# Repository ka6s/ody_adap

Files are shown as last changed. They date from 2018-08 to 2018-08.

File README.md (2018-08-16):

# Odyssey-II adapter
This is a break out board for the Oddyssey II HPSDR transceiver.

I have done a couple of versions of this - the final configuration has a SPI output, but also
expects to be able to support a x4 HERMES style filter set up.  There is also a custom 
connector on here to drive the companion antenna switch. Note that there is only ONE 
ANT output available - so only two antenna ports are supported.

Lots of copies of PTT-out..can't have too many of those!

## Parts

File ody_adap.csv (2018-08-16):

Id | Designator | Package | Quantity | Designation | Supplier and ref
1 | J1 | DB15_Male_HighDensity | 1 | DB15_Male_HighDensity
2 | R5,R1,R3,R4,R6,R7,R8,R9,R10,R11,R12 | R_1206_HandSoldering | 11 | 10K
3 | C6,C9,C12 | C_1210_HandSoldering | 3 | 100uF
4 | C7,C10,C13 | C_1210_HandSoldering | 3 | 1uF
5 | C8,C11 | C_1206_HandSoldering | 2 | 0.1uF
6 | C14 | C_1206 | 1 | 0.1uF
7 | CON1 | BARREL_JACK | 1 | BARREL_JACK
8 | P1,P2,P3,P4,P8,P9,P10 | Pin_Header_Straight_1x03 | 7 | CONN_01X03
9 | P5,P6,P7 | Pin_Header_Straight_2x04 | 3 | CONN_02X04
10 | Q1,Q2,Q3 | TO-92_Molded_Narrow | 3 | Q_NMOS_SGD
11 | U1,U2 | DIP-16_W7.62mm | 2 | ULN2003
12 | J2 | Pin_Header_Straight_1x06_Pitch2.54mm | 1 | Conn_01x06
13 | P11 | Pin_Header_Straight_1x03_Pitch2.54mm | 1 | CONN_01X03
14 | P12 | Pin_Header_Straight_1x05_Pitch2.54mm | 1 | CONN_01X05

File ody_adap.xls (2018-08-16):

Id | Designator | Package | Quantity | Designation | Mouser
1 | J1 | DB15_Male_HighDensity | 1 | DB15_Male_HighDensity
2 | R5,R1,R3,R4,R6,R7,R8,R9,R10,R11,R12 | R_1206_HandSoldering | 11 | 10K | 66-PCFW1206LF031002B (https://www.mouser.com/ProductDetail/Welwyn-Components-TT-Electronics/PCF-W1206LF-03-1002-B-P-LT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)
3 | C6,C9,C12 | C_1210_HandSoldering | 3 | 100uF | 963-EMK325ABJ107MM-T (https://www.mouser.com/ProductDetail/Taiyo-Yuden/EMK325ABJ107MM-T)
4 | C7,C10,C13 | C_1210_HandSoldering | 3 | 1uF | 77-VJ1206Y105KXQTBC (https://www.mouser.com/QuickViewProdDetail.aspx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)
5 | C8,C11 | C_1206_HandSoldering | 2 | 0.1uF | 963-QMK316BJ104KL-T (https://www.mouser.com/ProductDetail/Taiyo-Yuden/QMK316BJ104KL-T)
6 | C14 | C_1206 | 1 | 0.1uF | 963-QMK316BJ104KL-T (https://www.mouser.com/ProductDetail/Taiyo-Yuden/QMK316BJ104KL-T)
7 | CON1 | BARREL_JACK | 1 | BARREL_JACK | 490-PJ-002BH (https://www.mouser.com/QuickViewProdDetail.aspx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)
8 | P1,P2,P3,P4,P8,P9,P10 | Pin_Header_Straight_1x03 | 7 | CONN_01X03
9 | P5,P6,P7 | Pin_Header_Straight_2x04 | 3 | CONN_02X04
10 | Q1,Q2,Q3 | TO-92_Molded_Narrow | 3 | Q_NMOS_SGD | 512-2N7000 (https://www.mouser.com/QuickViewProdDetail.aspx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)
11 | U1,U2 | DIP-16_W7.62mm | 2 | ULN2003 | 511-ULN2003A (https://www.mouser.com/ProductDetail/STMicroelectronics/ULN2003A?qs=sGAEpiMZZMvAvBNgSS9LqkBZ7AC8MBp%2F)
12 | J2 | Pin_Header_Straight_1x06_Pitch2.54mm | 1 | Conn_01x06
13 | P11 | Pin_Header_Straight_1x03_Pitch2.54mm | 1 | CONN_01X03
14 | P12 | Pin_Header_Straight_1x05_Pitch2.54mm | 1 | CONN_01X05

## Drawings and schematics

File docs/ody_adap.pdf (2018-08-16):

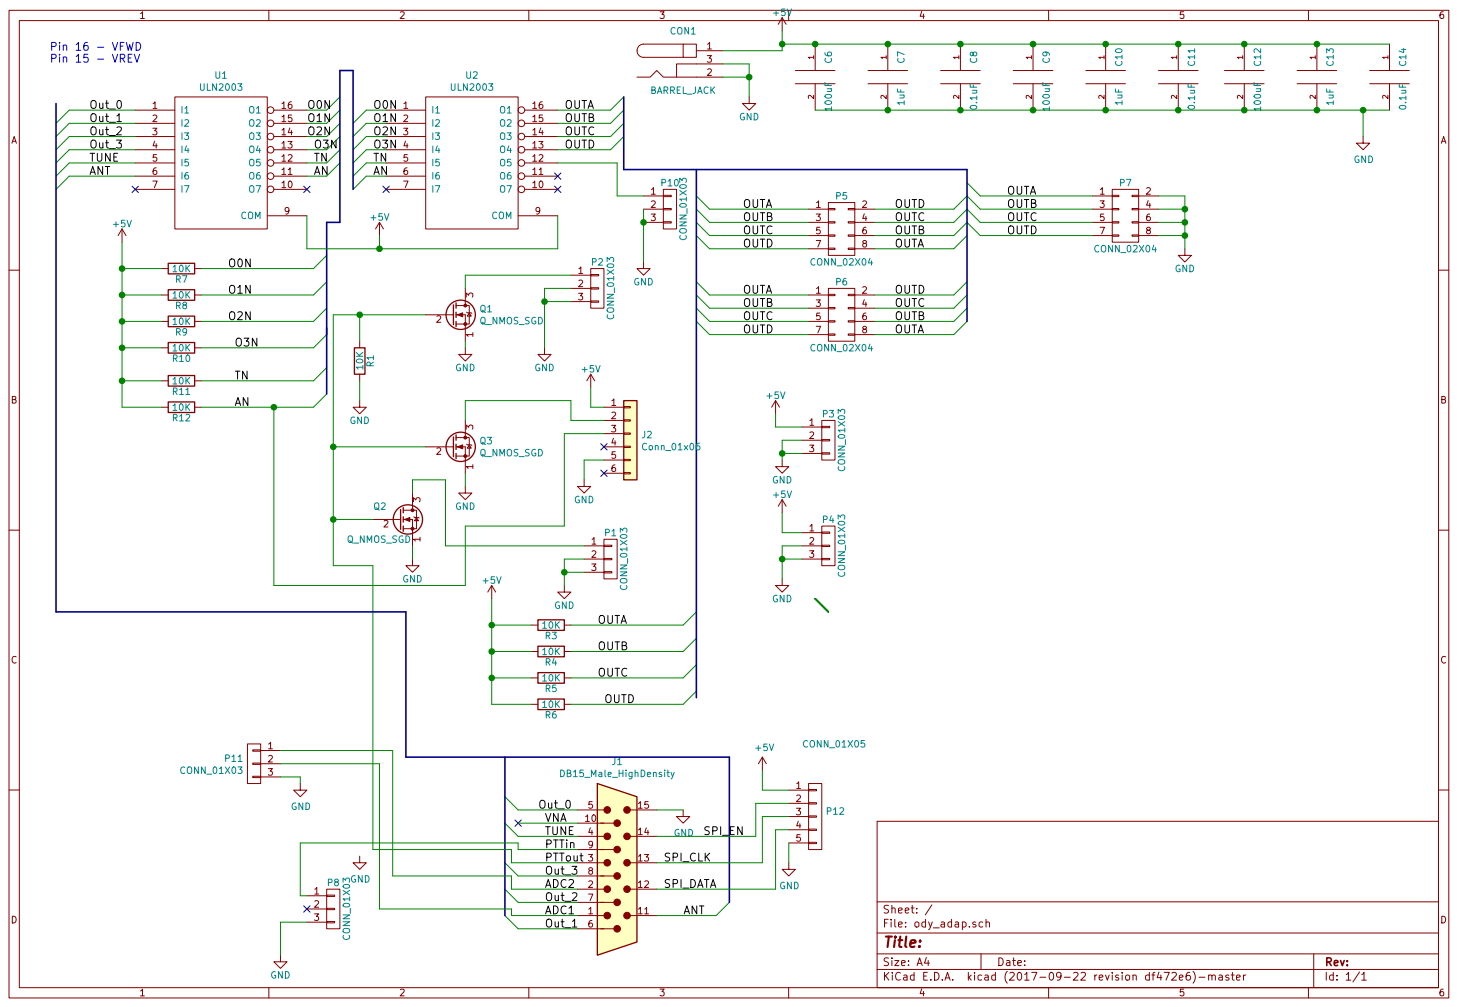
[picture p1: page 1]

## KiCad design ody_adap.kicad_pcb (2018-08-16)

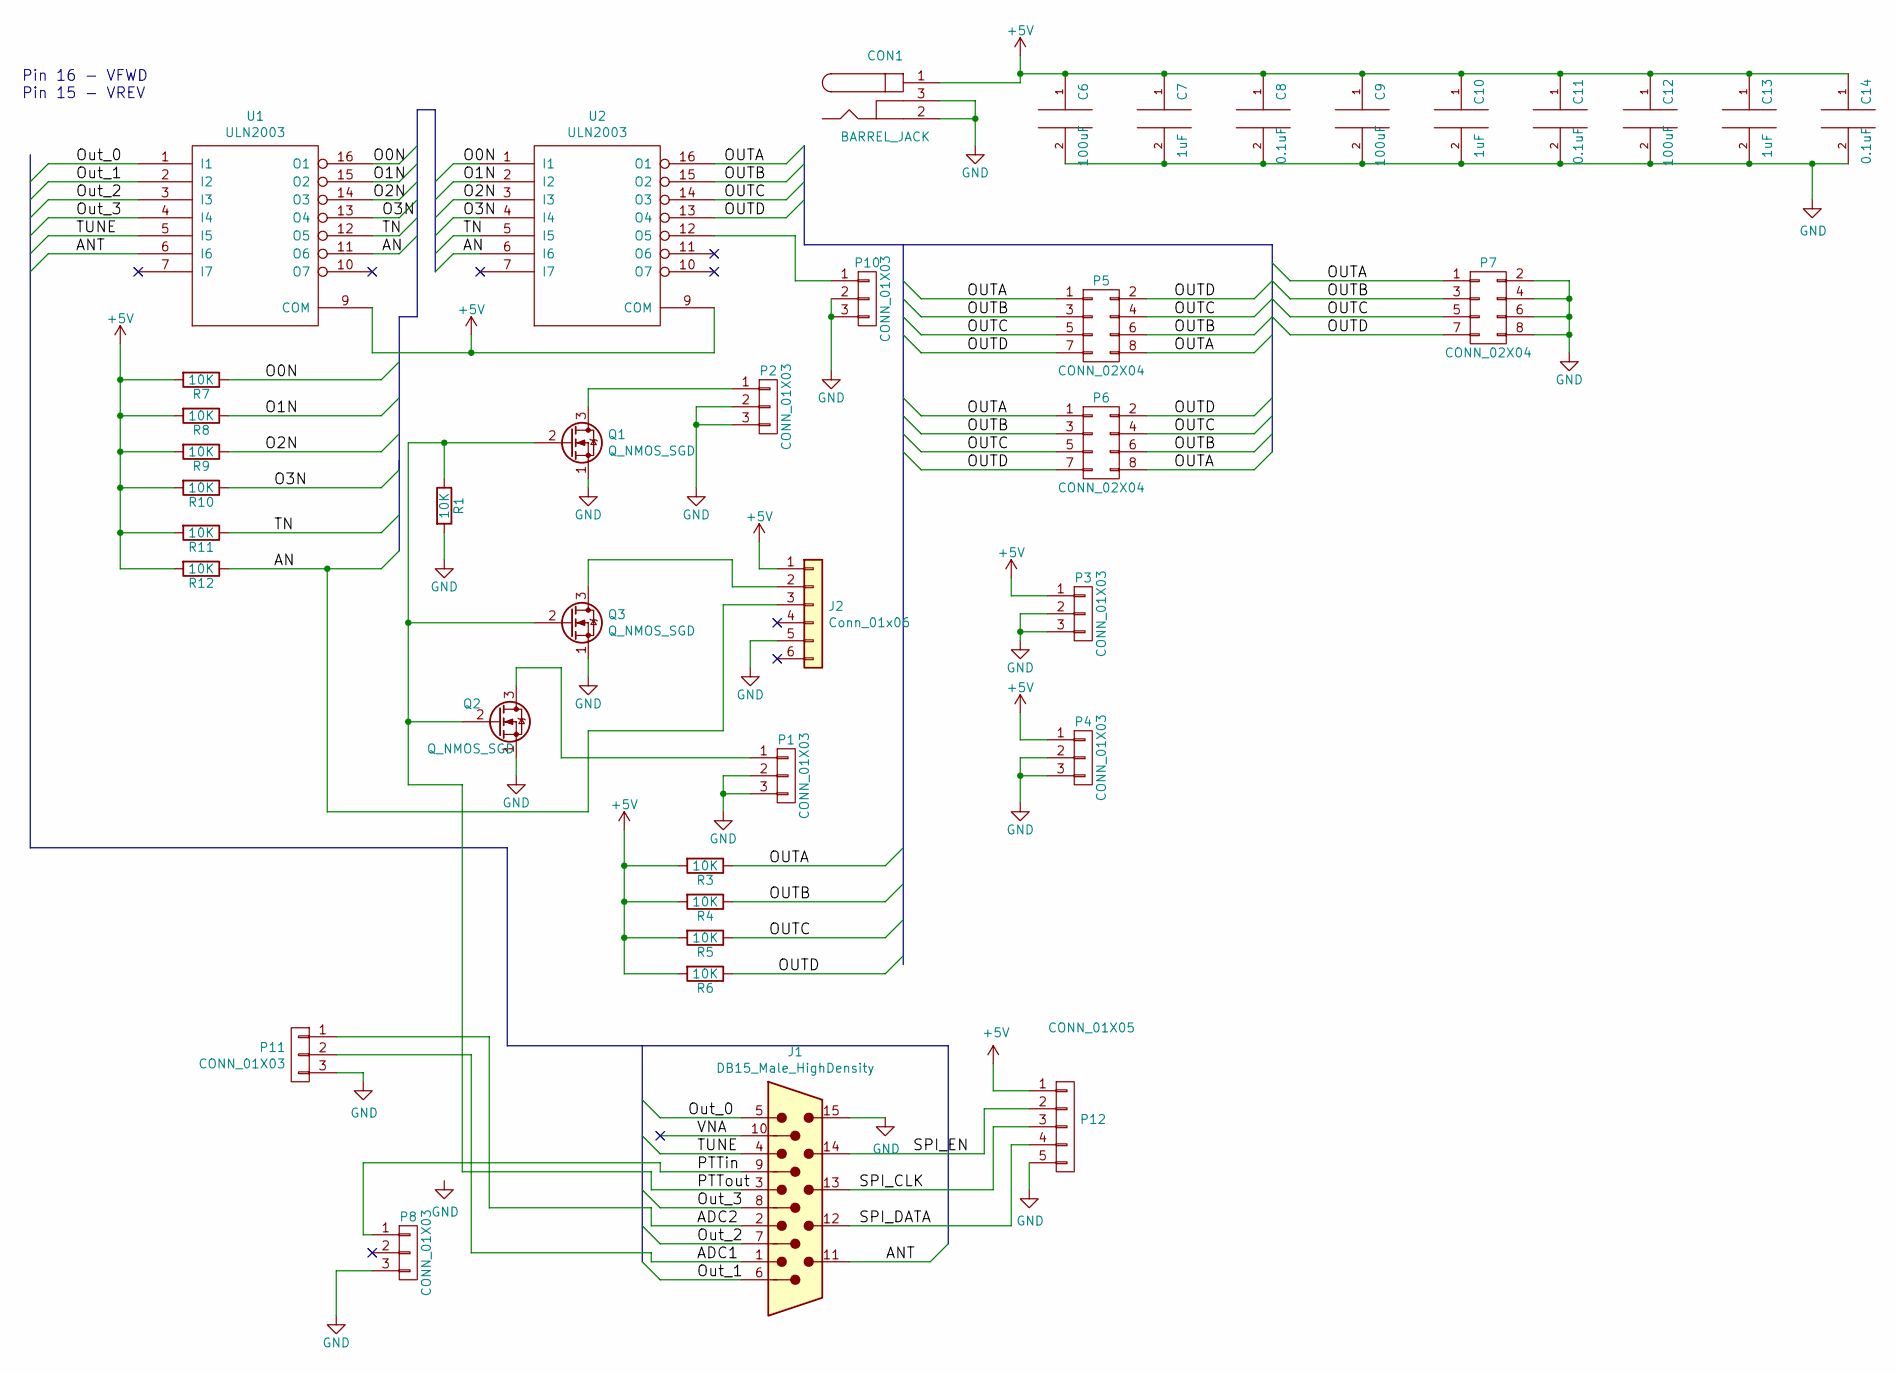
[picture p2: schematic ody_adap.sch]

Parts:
C6, C9, C12: 100uF; C_1210_HandSoldering
C7, C10, C13: 1uF; C_1210_HandSoldering
C8, C11: 0.1uF; C_1206_HandSoldering
C14: 0.1uF; C_1206
CON1: BARREL_JACK
J1: DB15_Male_HighDensity
J2: Conn_01x06; Pin_Header_Straight_1x06_Pitch2.54mm
P1, P2, P3, P4, P8, P10: CONN_01X03; Pin_Header_Straight_1x03
P5, P6, P7: CONN_02X04; Pin_Header_Straight_2x04
P11: CONN_01X03; Pin_Header_Straight_1x03_Pitch2.54mm
P12: CONN_01X05; Pin_Header_Straight_1x05_Pitch2.54mm
Q1, Q2, Q3: Q_NMOS_SGD; TO-92_Molded_Narrow
R1, R3, R4, R5, R6, R7, R8, R9, R10, R11, R12: 10K; R_1206_HandSoldering
U1, U2: ULN2003; DIP-16_W7.62mm

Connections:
+5V: C6.1, C7.1, C8.1, C9.1, C10.1, C11.1, C12.1, C13.1, C14.1, CON1.1, J2.1, P3.1, P4.1, P12.1, R3.2, R4.2, R5.2, R6.2, R7.2, R8.2, R9.2, R10.2, R11.2, R12.2, U1.9 (COM), U2.9 (COM)
/ADC1: J1.1, P11.2
/ADC2: J1.2, P11.1
/AN: J2.3, R12.1, U1.11 (O6), U2.6 (I6)
/ANT: J1.11, U1.6 (I6)
/O0N: R7.1, U1.16 (O1), U2.1 (I1)
/O1N: R8.1, U1.15 (O2), U2.2 (I2)
/O2N: R9.1, U1.14 (O3), U2.3 (I3)
/O3N: R10.1, U1.13 (O4), U2.4 (I4)
/OUTA: P5.1, P5.8, P6.1, P6.8, P7.1, R3.1, U2.16 (O1)
/OUTB: P5.3, P5.6, P6.3, P6.6, P7.3, R4.1, U2.15 (O2)
/OUTC: P5.4, P5.5, P6.4, P6.5, P7.5, R5.1, U2.14 (O3)
/OUTD: P5.2, P5.7, P6.2, P6.7, P7.7, R6.1, U2.13 (O4)
/Out_0: J1.5, U1.1 (I1)
/Out_1: J1.6, U1.2 (I2)
/Out_2: J1.7, U1.3 (I3)
/Out_3: J1.8, U1.4 (I4)
/PTTin: J1.9, P8.1
/PTTout: J1.3, Q1.2 (G), Q2.2 (G), Q3.2 (G), R1.1
/SPI_CLK: J1.13, P12.3
/SPI_DATA: J1.12, P12.4
/SPI_EN: J1.14, P12.2
/TN: R11.1, U1.12 (O5), U2.5 (I5)
/TUNE: J1.4, U1.5 (I5)
/VNA: J1.10
GND: C6.2, C7.2, C8.2, C9.2, C10.2, C11.2, C12.2, C13.2, C14.2, CON1.2, CON1.3, J1.15, J2.5, P1.2, P1.3, P2.2, P2.3, P3.2, P3.3, P4.2, P4.3, P7.2, P7.4, P7.6, P7.8, P8.3, P10.2, P10.3, P11.3, P12.5, Q1.1 (S), Q2.1 (S), Q3.1 (S), R1.2, U1.8 (GND), U2.8 (GND); also elsewhere on the board
unnamed: J2.2, Q3.3 (D)
unnamed: P1.1, Q2.3 (D)
unnamed: P2.1, Q1.3 (D)
unnamed: P10.1, U2.12 (O5)

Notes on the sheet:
Pin 16 - VFWD Pin 15 - VREV

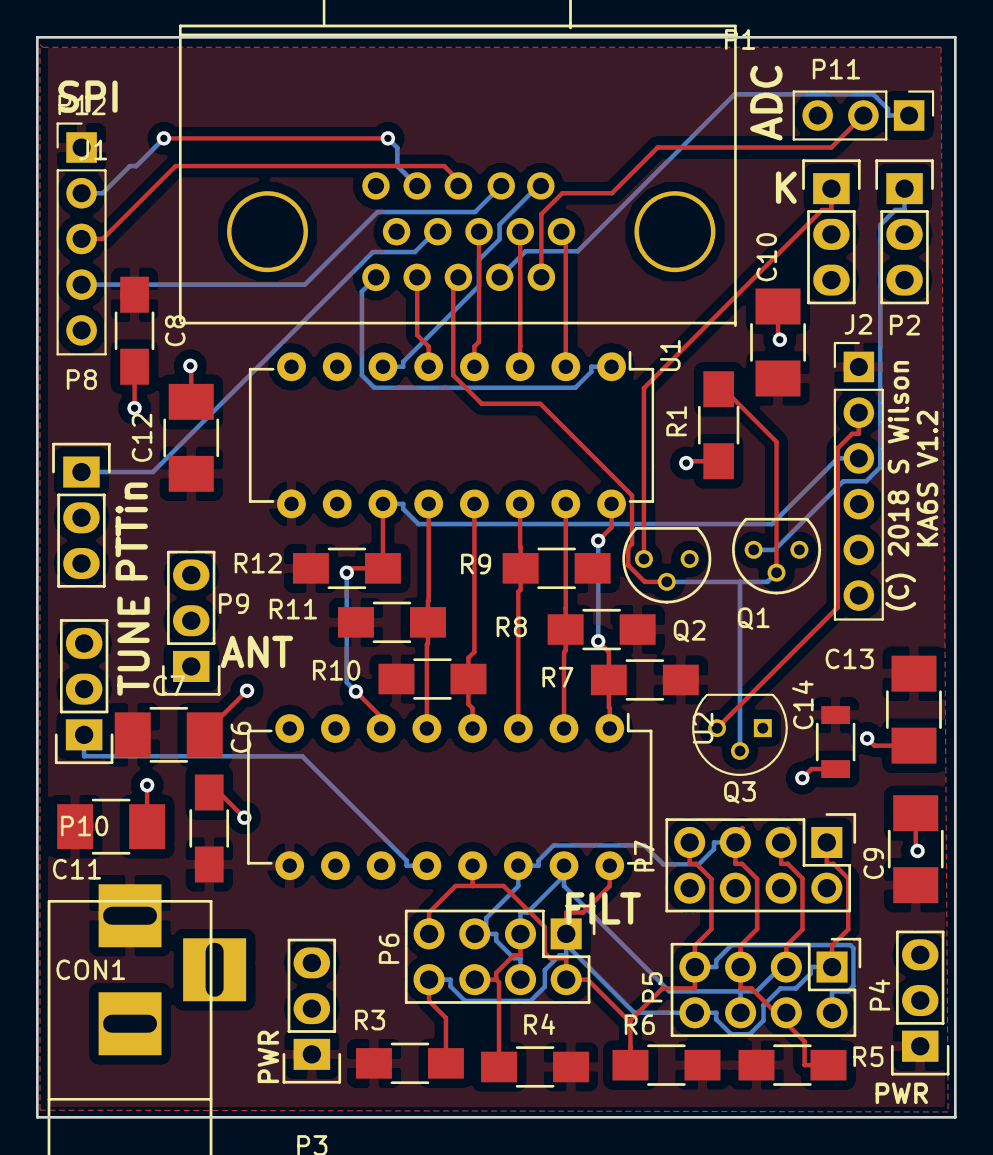
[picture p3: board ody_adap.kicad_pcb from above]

Board: 2 copper layers, 51.0 x 60.0 mm, 40 parts (0 on the bottom side), 29 nets.

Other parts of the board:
P9: CONN_01X03; Pin_Header_Straight_1x03

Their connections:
GND: P9.3; also elsewhere on the board

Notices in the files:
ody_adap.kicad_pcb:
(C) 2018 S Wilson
